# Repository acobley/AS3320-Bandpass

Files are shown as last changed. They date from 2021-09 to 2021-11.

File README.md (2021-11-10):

View this project on [CADLAB.io](https://cadlab.io/project/24867). 

# AS3320-Bandpass
This is a bandpass filter with CV control of the resonce based on a single  AS3320

Status: In Design

Board: No Board sent to manfacturer.

## Licence and attribution
CC4.0

Based on the work by forestcaver/Analog-Voice (github)

## Major aditions
* Added CV on Resonance
* Moved to larger components (0804)
* Added more inputs and input mixer out.

## History
as3320-BandPass-Dev2 10/Nov/2021 This board is untested. D6 repositioned.

as3320-BandPass-Dev1  2/oct/2021 D6 is shorted to FM level POT Do NOT USE (To use, a TTH D6 can be substituted  betweenthe output pin and ground.

10/Nov/2021 Rec2021 Recieved and will be built with above botch. 

as3320-BandPass Layout version

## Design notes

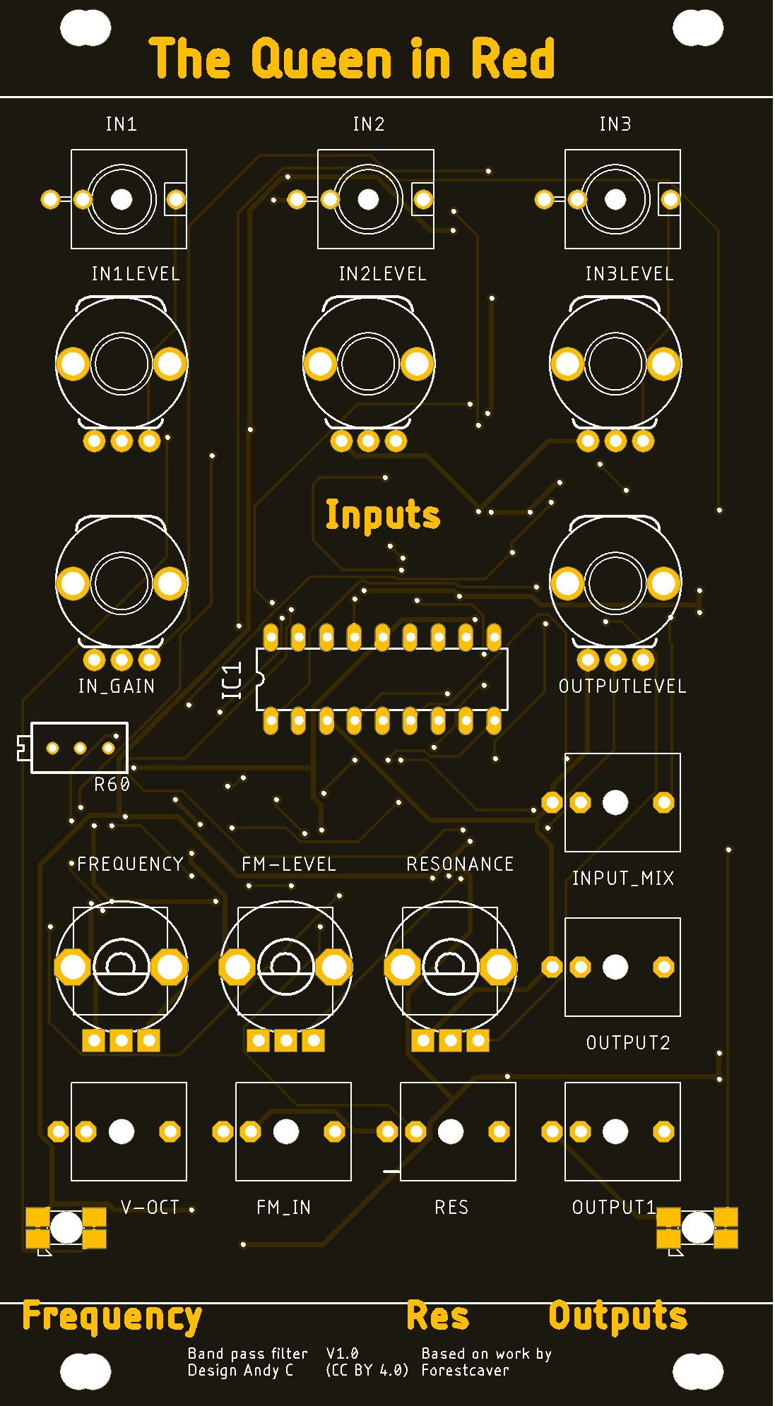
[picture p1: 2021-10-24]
as3320-BandPass-Dev1.png

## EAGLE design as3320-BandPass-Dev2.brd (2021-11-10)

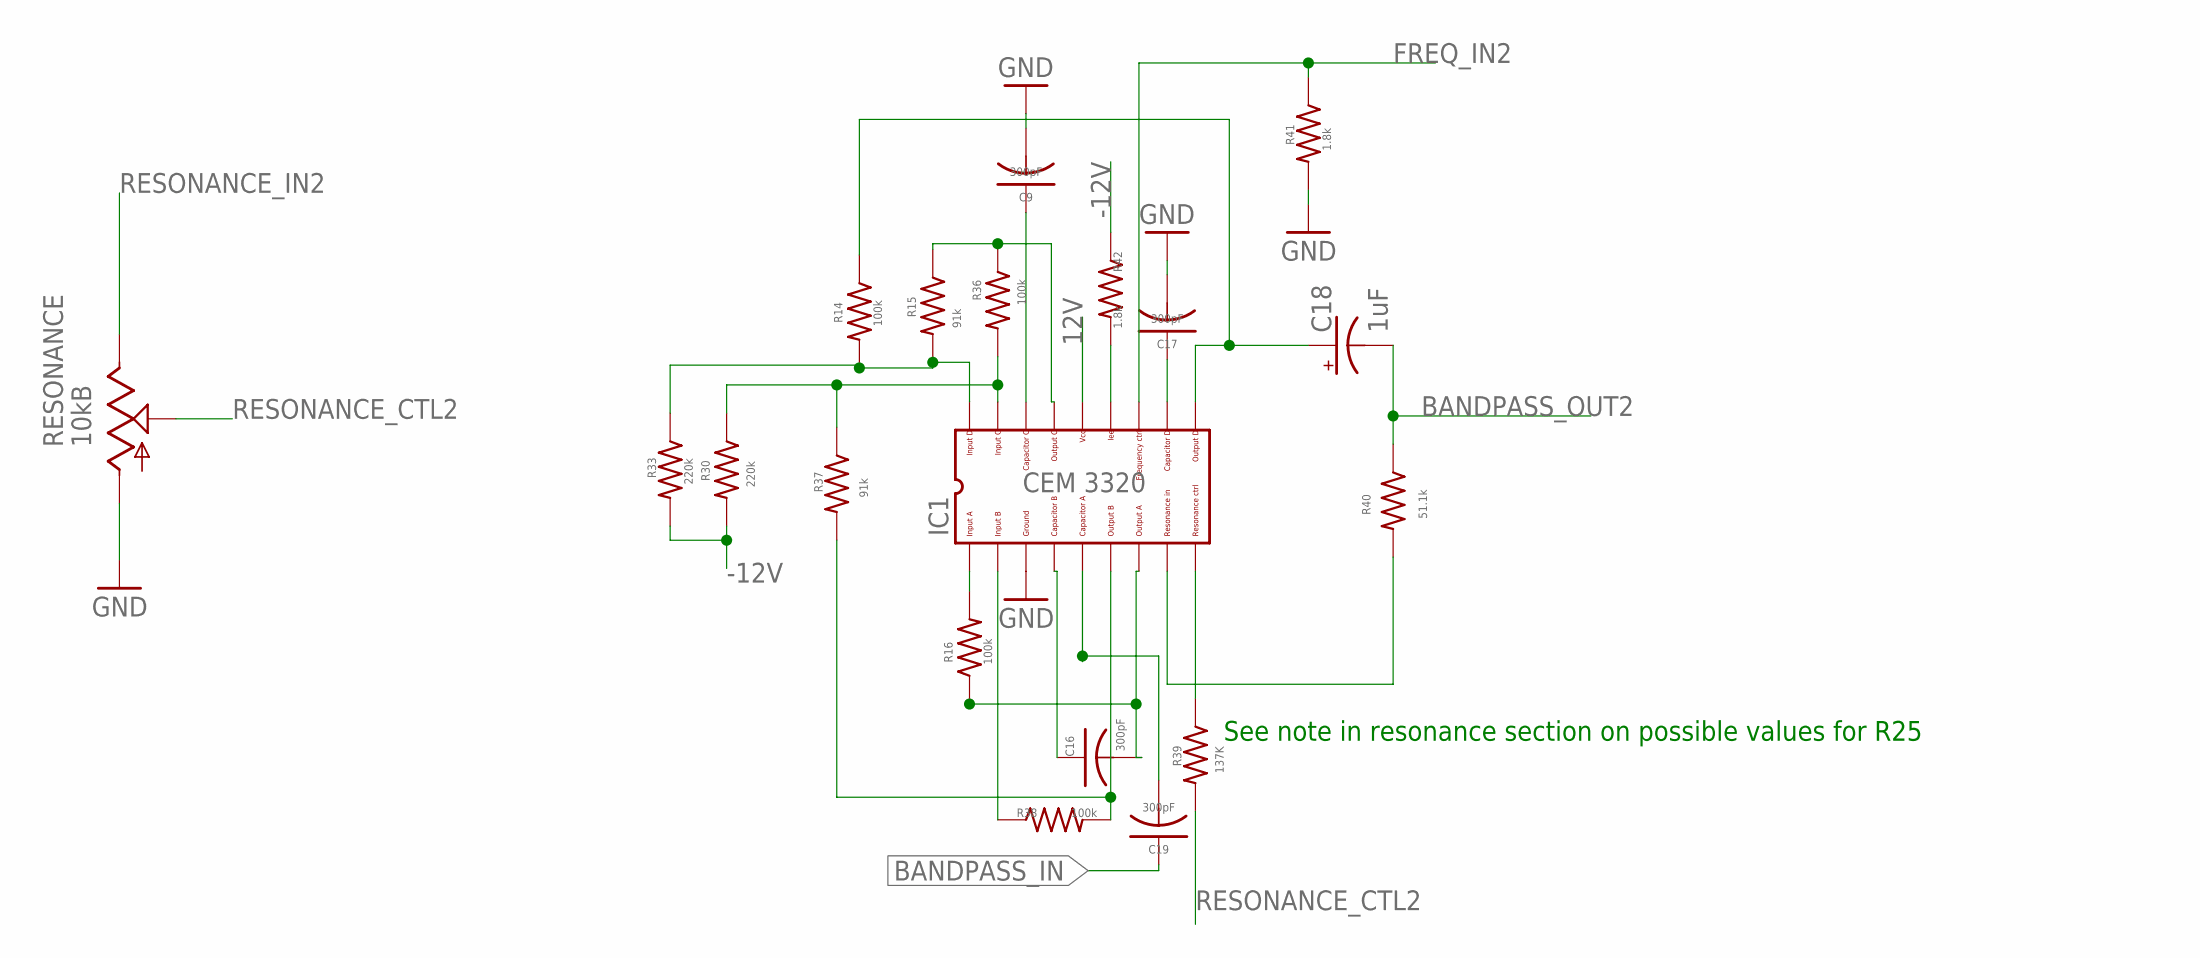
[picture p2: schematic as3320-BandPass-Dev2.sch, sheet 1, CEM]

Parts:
C9, C16, C17, C19: 300pF; C0805K
C18: 1uF; PANASONIC_B
IC1: CEM3320; DIL18
R14, R16, R36, R38: 100k; GMSN_M0805
R15, R37: 91k; GMSN_M0805
R30, R33: 220k; GMSN_M0805
R39: 137K; GMSN_M0805
R40: 51.1k; GMSN_M0805
R41, R42: 1.8k; GMSN_M0805
RESONANCE: 10kB; ALPS_POT_VERTICAL

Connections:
12V: IC1.14; also elsewhere on the board
-12V: R30.2, R33.2, R42.1; also elsewhere on the board
BANDPASS_IN: C19.1; also elsewhere on the board
BANDPASS_OUT2: C18.-, R40.1; also elsewhere on the board
FREQ_IN2: IC1.12, R41.1; also elsewhere on the board
GND: C9.2, C17.2, IC1.3, R41.2, RESONANCE.P$3 (A); also elsewhere on the board
unnamed: C17.1, IC1.11
unnamed: IC1.9, R39.1
unnamed: IC1.8, R40.2
unnamed: IC1.13, R42.2
unnamed: C9.1, IC1.16
unnamed: C18.+, IC1.10, R14.1
unnamed: C19.2, IC1.5
unnamed: C16.2, IC1.7, R16.1
unnamed: C16.1, IC1.4
unnamed: IC1.2, R38.1
unnamed: IC1.6, R37.2, R38.2
unnamed: IC1.1, R16.2
unnamed: IC1.17, R30.1, R36.2, R37.1
unnamed: IC1.15, R15.1, R36.1
unnamed: IC1.18, R14.2, R15.2, R33.1
RESONANCE_CTL2: R39.2, RESONANCE.P$2 (S)
RESONANCE_IN2: RESONANCE.P$1 (E); also elsewhere on the board

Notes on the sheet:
See note in resonance section on possible values for R25

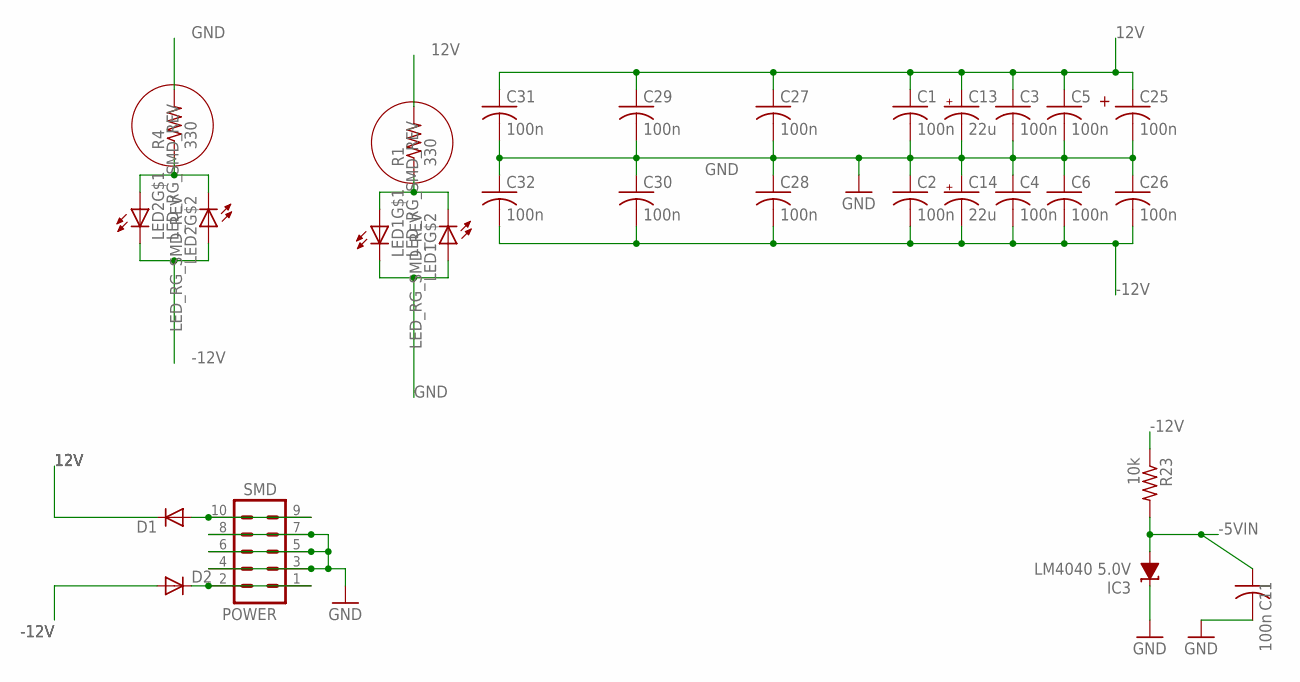
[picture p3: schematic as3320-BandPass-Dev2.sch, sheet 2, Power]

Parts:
C1, C2, C3, C4, C5, C6, C25, C26, C27, C28, C29, C30, C31, C32: 100n; C0805K
C11: 100n; GMSN_C0805K
C13, C14: 22u; PANASONIC_B
D1, D2: 1N5819HW; SOD123
IC3: LM4040 5.0V; DBZ_R-PDSO-G3
LED1, LED2: LED_RG_SMD_REV; LSG_T77K
POWER: SMD; 2X5-SHROUDED_SMD
R1, R4: 330; GMSN_M0805
R23: 10k; GMSN_M0805

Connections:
12V: C1.1, C3.1, C5.1, C13.+, C25.1, C27.1, C29.1, C31.1, D1.C, R1.2; also elsewhere on the board
-5VIN: C11.1, IC3.2 (A), R23.2; also elsewhere on the board
-12V: C2.2, C4.2, C6.2, C14.-, C26.2, C28.2, C30.2, C32.2, D2.A, LED2.1 (C), LED2.4 (A), R23.1; also elsewhere on the board
-12V-P: D2.C, POWER.1, POWER.2
GND: C1.2, C2.1, C3.2, C4.1, C5.2, C6.1, C11.2, C13.-, C14.+, C25.2, C26.1, C27.2, C28.1, C29.2, C30.1, C31.2, C32.1, IC3.1 (C), LED1.1 (C), LED1.4 (A), POWER.3, POWER.4, POWER.5, POWER.6, POWER.7, POWER.8, R4.2; also elsewhere on the board
unnamed: D1.A, POWER.9, POWER.10
unnamed: LED2.2 (A), LED2.3 (C), R4.1
unnamed: LED1.2 (A), LED1.3 (C), R1.1

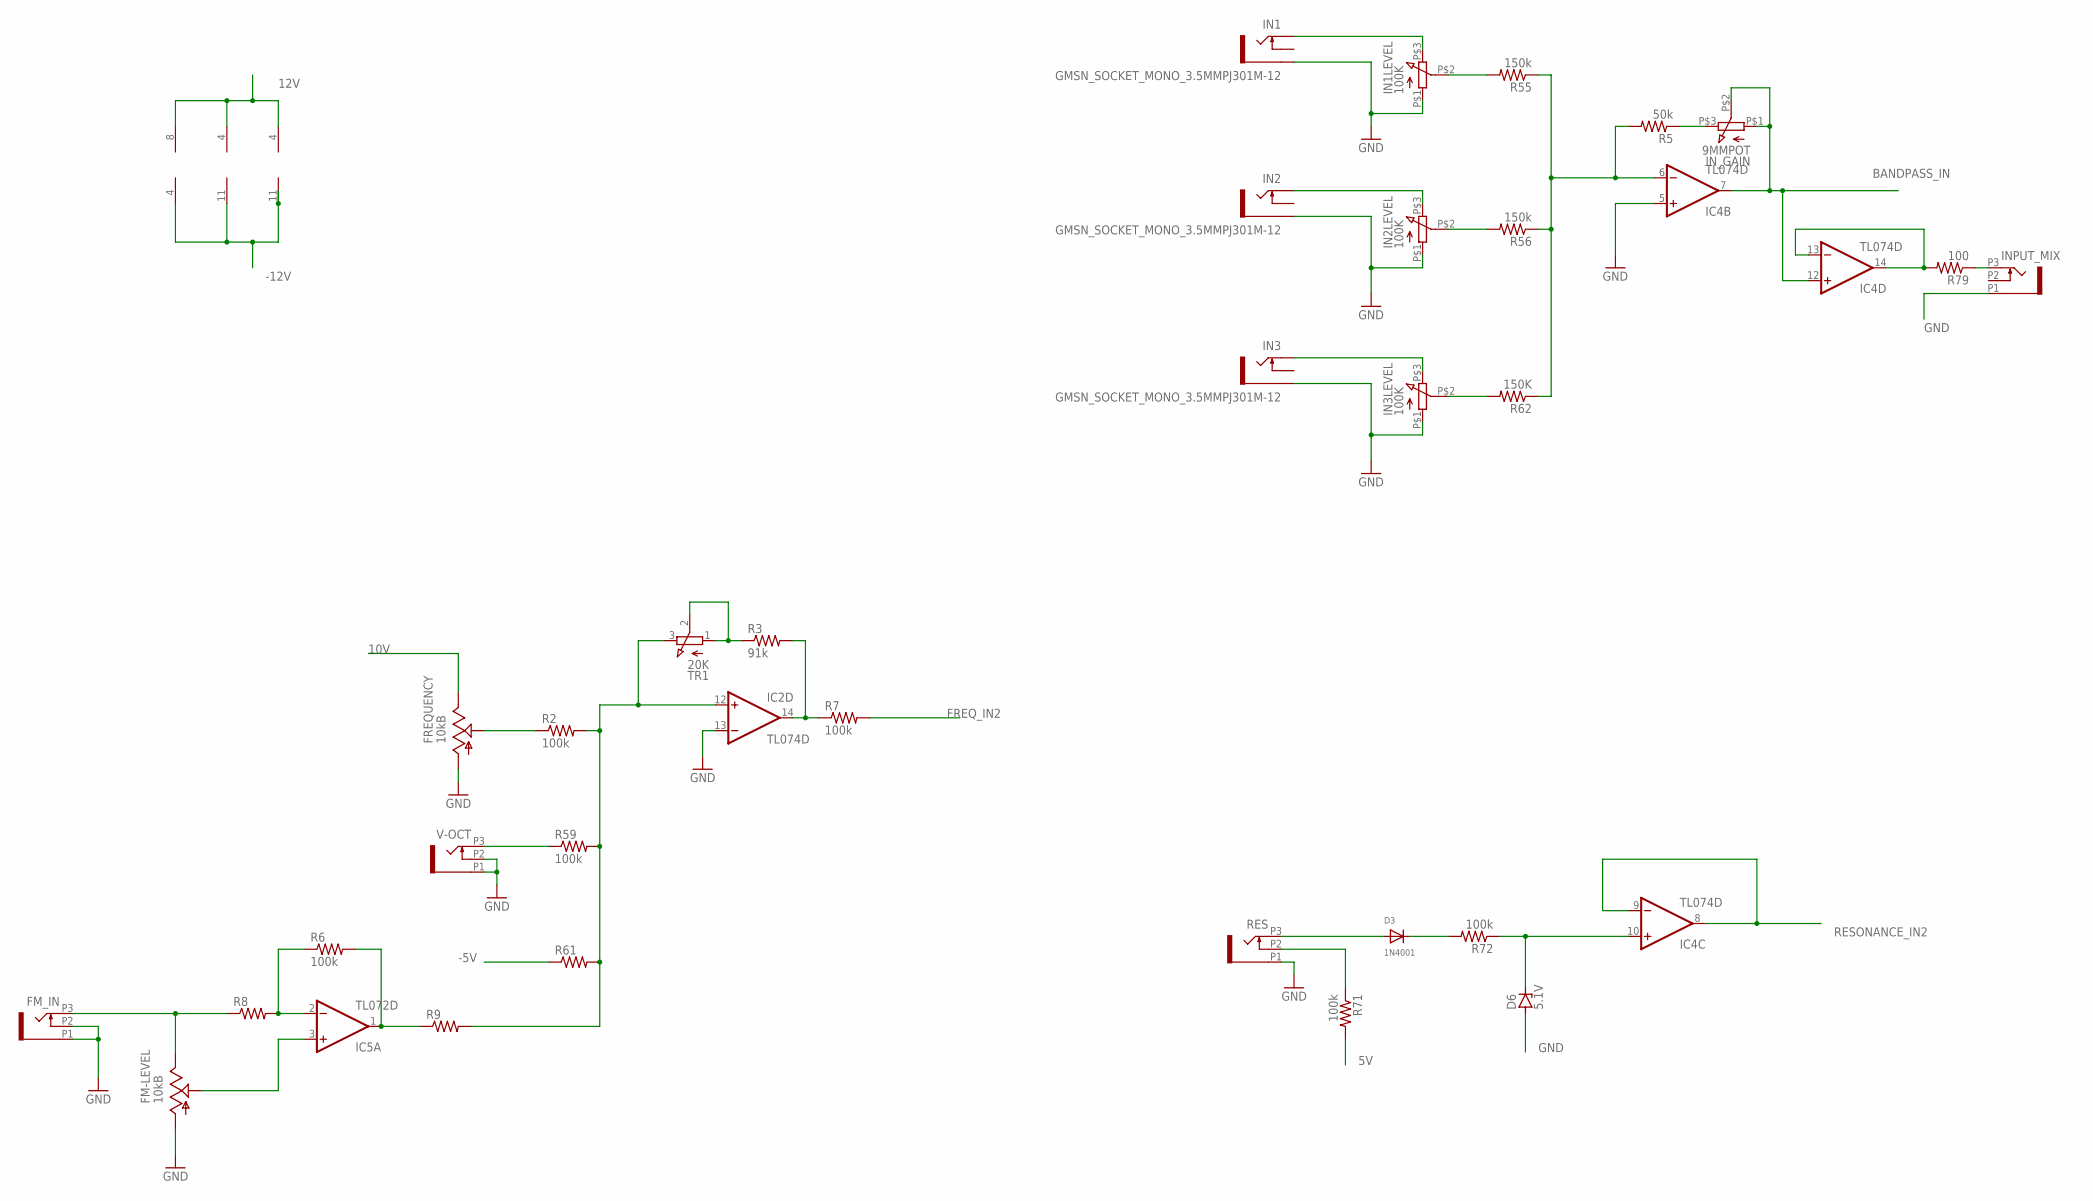
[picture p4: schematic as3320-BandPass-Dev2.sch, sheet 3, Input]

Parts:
D3: 1N4001; SMADIODE
D6: 5.1V; SOT23
FM-LEVEL: 10kB; ALPS_POT_VERTICAL
FM_IN: PJ301_THONKICONN6; WQP_PJ_301M6
FREQUENCY: 10kB; ALPS_POT_VERTICAL
IC2, IC4: TL074D; SO14
IC5: TL072D; SO08
IN1, IN2, IN3: GMSN_SOCKET_MONO_3.5MMPJ301M-12; GMSN_PJ301M-12
IN1LEVEL, IN2LEVEL, IN3LEVEL: 100K; POT
INPUT_MIX: PJ301_THONKICONN6; WQP_PJ_301M6
IN_GAIN: 9MMPOT; POT
R2, R6, R7, R59, R72: 100k; GMSN_M0805
R3: 91k; GMSN_M0805
R5: 50k; GMSN_M0805
R8, R9, R61: 62k; GMSN_M0805
R55, R56: 150k; R0805
R62: 150K; R0805
R71: 100k; R0805
R79: 100; GMSN_M0805
RES: PJ301_THONKICONN6; WQP_PJ_301M6
TR1: 20K; TRIMMER_TH3
V-OCT: PJ301_THONKICONN6; WQP_PJ_301M6

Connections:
5V: R71.2; also elsewhere on the board
10V: FREQUENCY.P$1 (E); also elsewhere on the board
12V: IC2.4 (V+), IC4.4 (V+), IC5.8 (V+); also elsewhere on the board
-5V: R61.1; also elsewhere on the board
-12V: IC2.11 (V-), IC4.11 (V-), IC5.4 (V-); also elsewhere on the board
BANDPASS_IN: IC4.7 (OUT), IC4.12 (+IN), IN_GAIN.P$1 (1), IN_GAIN.P$2 (2); also elsewhere on the board
FREQ_IN2: R7.2; also elsewhere on the board
GND: D6.1 (A), FM-LEVEL.P$3 (A), FM_IN.P1 (1), FM_IN.P2 (2), FREQUENCY.P$3 (A), IC2.13 (-IN), IC4.5 (+IN), IN1.GND (SLEEVE), IN1LEVEL.P$1 (1), IN2.GND (SLEEVE), IN2LEVEL.P$1 (1), IN3.GND (SLEEVE), IN3LEVEL.P$1 (1), INPUT_MIX.P1 (1), RES.P1 (1), V-OCT.P1 (1), V-OCT.P2 (2); also elsewhere on the board
unnamed: IC5.2 (-IN), R6.1, R8.2
unnamed: IC2.14 (OUT), R3.2, R7.1
unnamed: IC5.1 (OUT), R6.2, R9.1
unnamed: FREQUENCY.P$2 (S), R2.1
unnamed: FM-LEVEL.P$2 (S), IC5.3 (+IN)
unnamed: FM-LEVEL.P$1 (E), FM_IN.P3 (3), R8.1
unnamed: R71.1, RES.P2 (2)
unnamed: IC2.12 (+IN), R2.2, R9.2, R59.2, R61.2, TR1.3
unnamed: IN_GAIN.P$3 (3), R5.1
unnamed: R59.1, V-OCT.P3 (3)
unnamed: R3.1, TR1.1, TR1.2
unnamed: IN1.TIP, IN1LEVEL.P$3 (3)
unnamed: IN2.TIP, IN2LEVEL.P$3 (3)
unnamed: D3.A, RES.P3 (3)
unnamed: IN1LEVEL.P$2 (2), R55.2
unnamed: IN2LEVEL.P$2 (2), R56.2
unnamed: IN3.TIP, IN3LEVEL.P$3 (3)
unnamed: IN3LEVEL.P$2 (2), R62.2
unnamed: IC4.6 (-IN), R5.2, R55.1, R56.1, R62.1
unnamed: D3.C, R72.2
unnamed: D6.3 (C), IC4.10 (+IN), R72.1
unnamed: IC4.13 (-IN), IC4.14 (OUT), R79.2
unnamed: INPUT_MIX.P3 (3), R79.1
RESONANCE_IN2: IC4.8 (OUT), IC4.9 (-IN); also elsewhere on the board

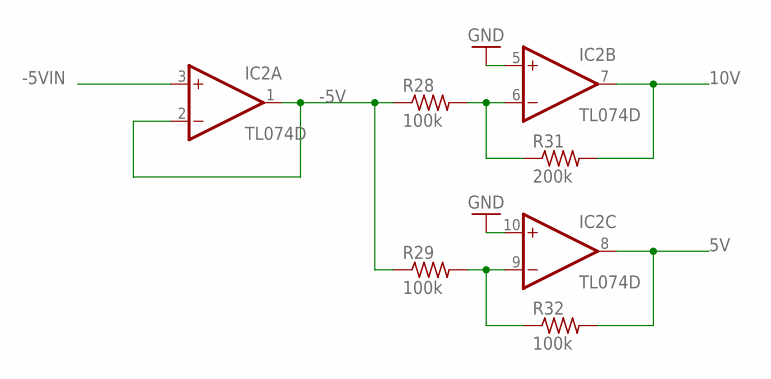
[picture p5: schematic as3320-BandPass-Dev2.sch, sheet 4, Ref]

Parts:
IC2: TL074D; SO14
R28, R29, R32: 100k; GMSN_M0805
R31: 200k; GMSN_M0805

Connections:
5V: IC2.8 (OUT), R32.2; also elsewhere on the board
10V: IC2.7 (OUT), R31.2; also elsewhere on the board
-5V: IC2.1 (OUT), IC2.2 (-IN), R28.1, R29.1; also elsewhere on the board
-5VIN: IC2.3 (+IN); also elsewhere on the board
GND: IC2.5 (+IN), IC2.10 (+IN); also elsewhere on the board
unnamed: IC2.9 (-IN), R29.2, R32.1
unnamed: IC2.6 (-IN), R28.2, R31.1

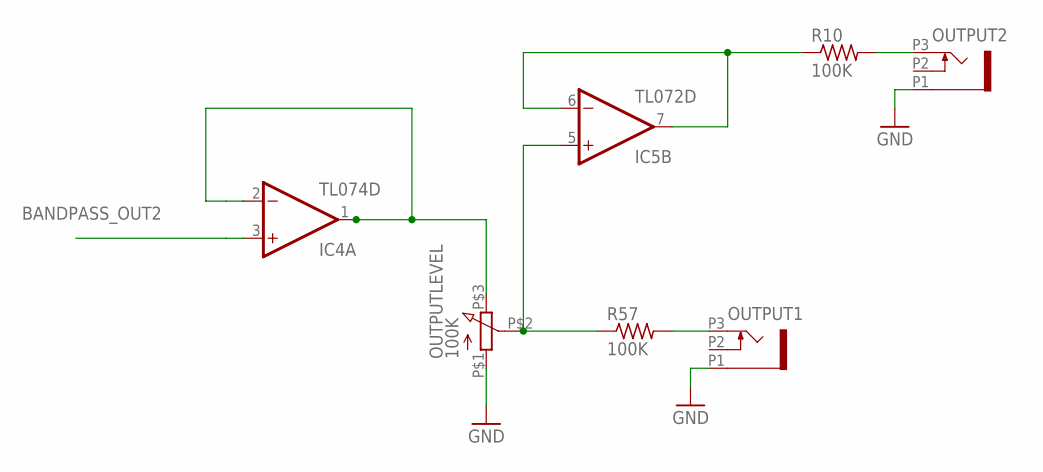
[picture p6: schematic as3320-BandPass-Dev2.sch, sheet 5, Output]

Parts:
IC4: TL074D; SO14
IC5: TL072D; SO08
OUTPUT1, OUTPUT2: PJ301_THONKICONN6; WQP_PJ_301M6
OUTPUTLEVEL: 100K; POT
R10, R57: 100K; GMSN_M0805

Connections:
BANDPASS_OUT2: IC4.3 (+IN); also elsewhere on the board
GND: OUTPUT1.P1 (1), OUTPUT2.P1 (1), OUTPUTLEVEL.P$1 (1); also elsewhere on the board
unnamed: IC5.5 (+IN), OUTPUTLEVEL.P$2 (2), R57.1
unnamed: IC5.6 (-IN), IC5.7 (OUT), R10.1
unnamed: IC4.1 (OUT), IC4.2 (-IN), OUTPUTLEVEL.P$3 (3)
O1: OUTPUT2.P3 (3), R10.2
O2: OUTPUT1.P3 (3), R57.2

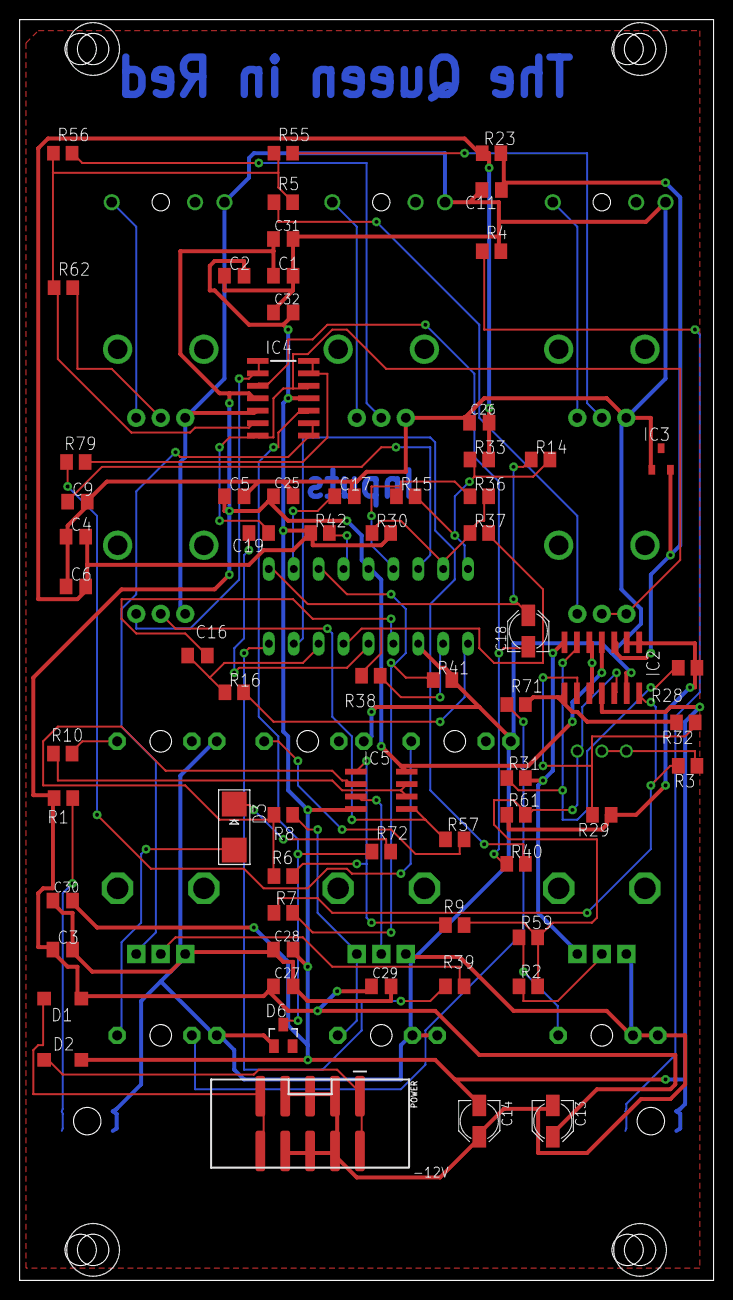
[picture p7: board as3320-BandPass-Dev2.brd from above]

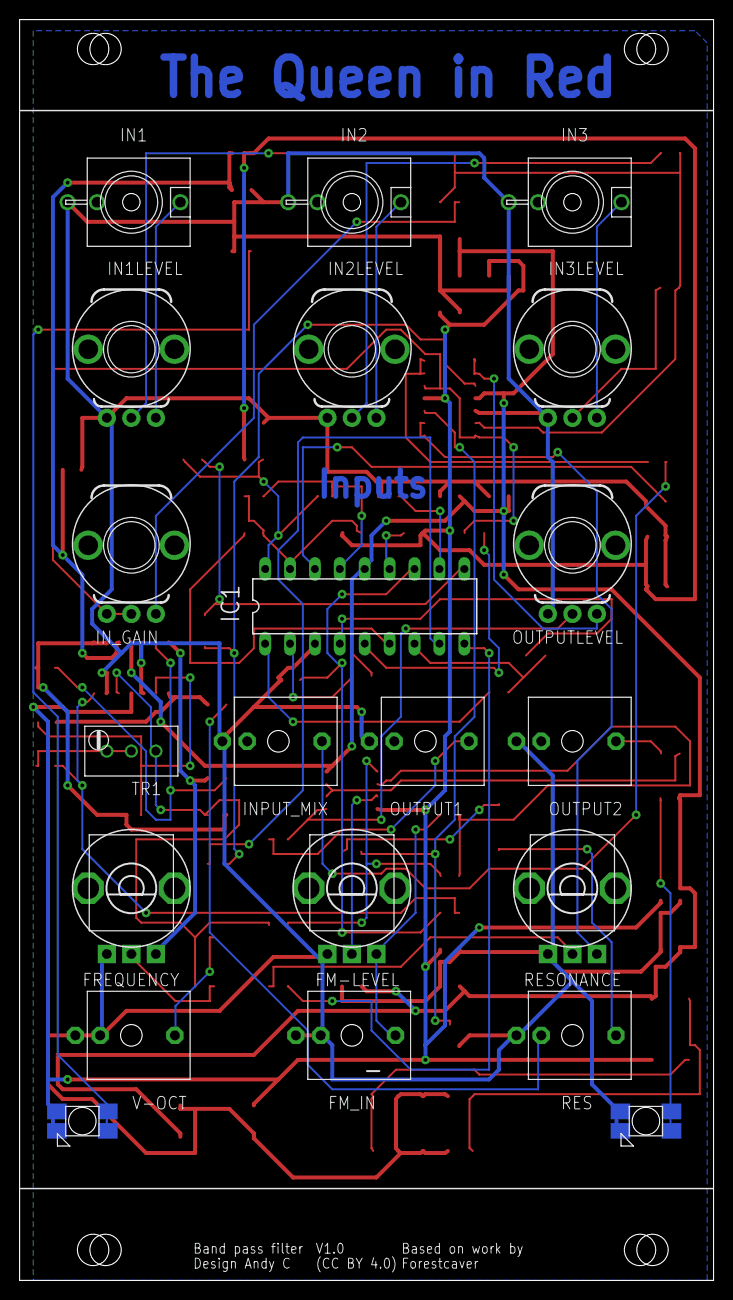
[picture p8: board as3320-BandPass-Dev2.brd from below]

Board: 2 copper layers, 70.8 x 128.6 mm, 92 parts (21 on the bottom side), 61 nets.

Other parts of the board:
U$2, U$3, U$4, U$5: MOUNTING_HOLE

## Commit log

2021-09-09 added Board and Schematic
    [as3320-BandPass.brd, as3320-BandPass.sch]
2021-09-09 Updated to include FM in
    [as3320-BandPass.brd, as3320-BandPass.sch]
2021-09-09 added power for IC5
    [as3320-BandPass.brd, as3320-BandPass.sch]
2021-10-21 De1 in evaluation
    [as3320-BandPass-Dev1.brd, as3320-BandPass-Dev1.sch]
2021-10-23 Added 2nd output
    [as3320-BandPass-Dev1.brd, as3320-BandPass-Dev1.sch]
2021-11-10 Dev 2 board added
    [as3320-BandPass-Dev2.brd, as3320-BandPass-Dev2.sch]

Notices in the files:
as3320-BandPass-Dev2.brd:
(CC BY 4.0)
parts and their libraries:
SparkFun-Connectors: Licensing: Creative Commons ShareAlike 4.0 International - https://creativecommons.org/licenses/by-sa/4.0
